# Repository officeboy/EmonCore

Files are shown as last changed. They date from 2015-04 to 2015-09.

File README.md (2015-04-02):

# EmonCore
Open Energy Monitor - All in One for the Spark Core/Photon

Based on work done in the [emonBase/NanodeRF](http://openenergymonitor.org/emon/emonBase/NanodeRF) project, Cinezaster porting [EmonLib](https://github.com/Cinezaster/EmonLib), and Nils Mattisson's [HttpClient](https://github.com/nmattisson/HttpClient) Library

This project aims in the same single unit direction as emonPi but sticks with arduino type programing and aims for a smaller form factor. 

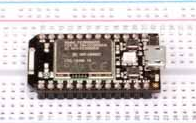
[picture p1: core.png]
spark_core


Currently there is no support for RFM12B or RFM69CW devices.  

### Features

- Built in WiFi
- 8 12-bit Analog Channels
- 73Mhz ARM Cortex M3
- Flash via Web

## Guide

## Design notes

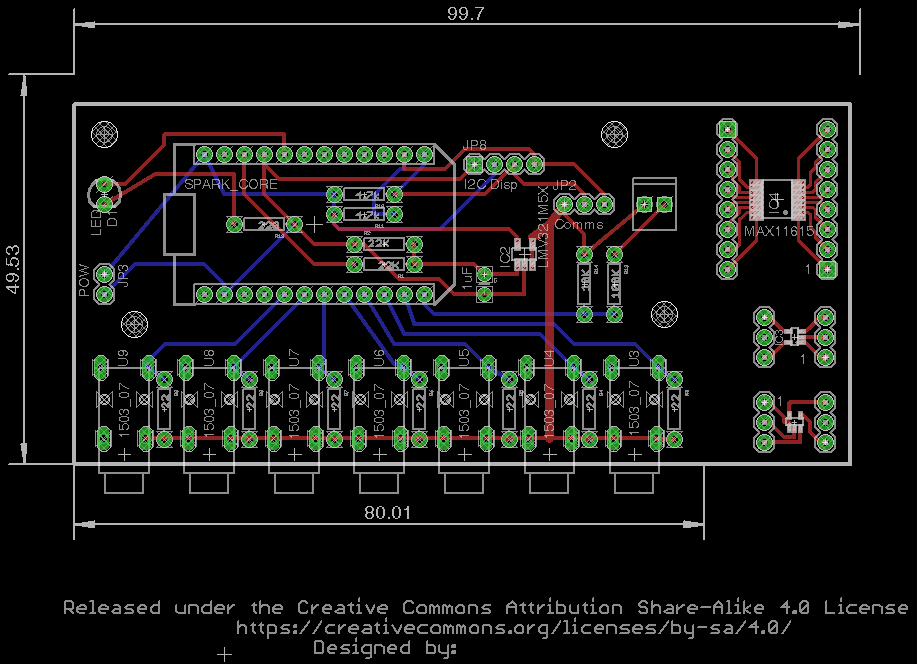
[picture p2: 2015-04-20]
hardware/core_pcb.png

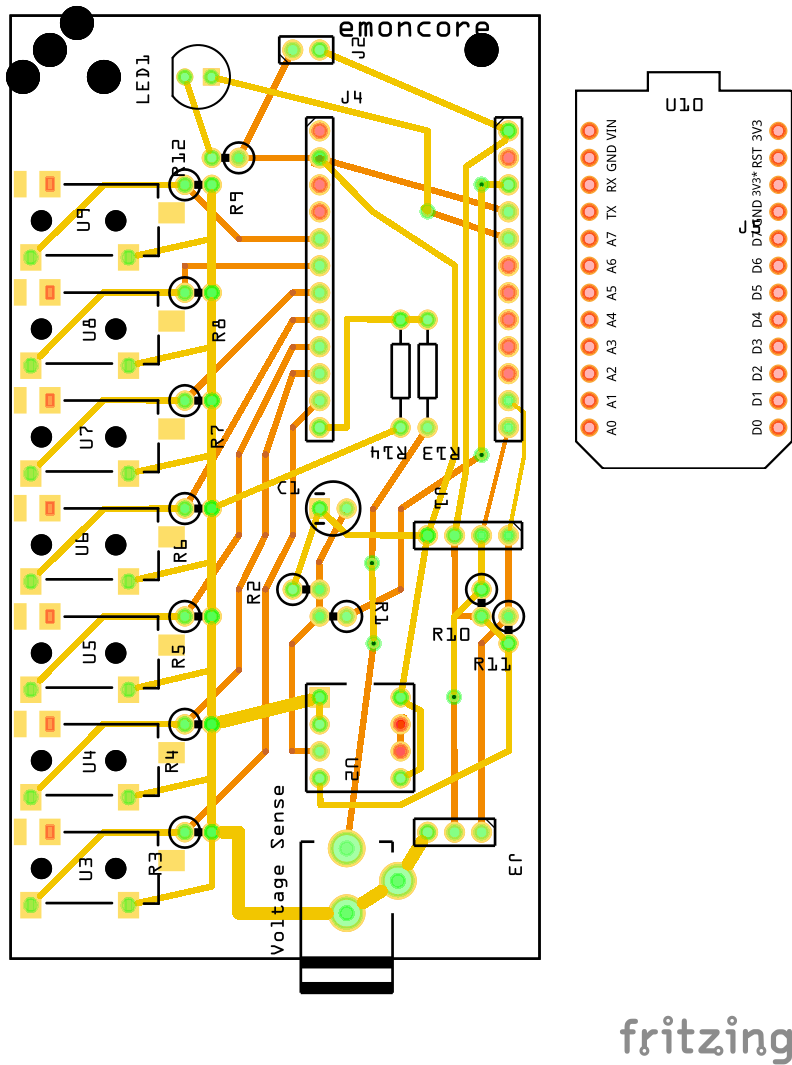
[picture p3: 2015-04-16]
hardware/emoncore_pcb.png

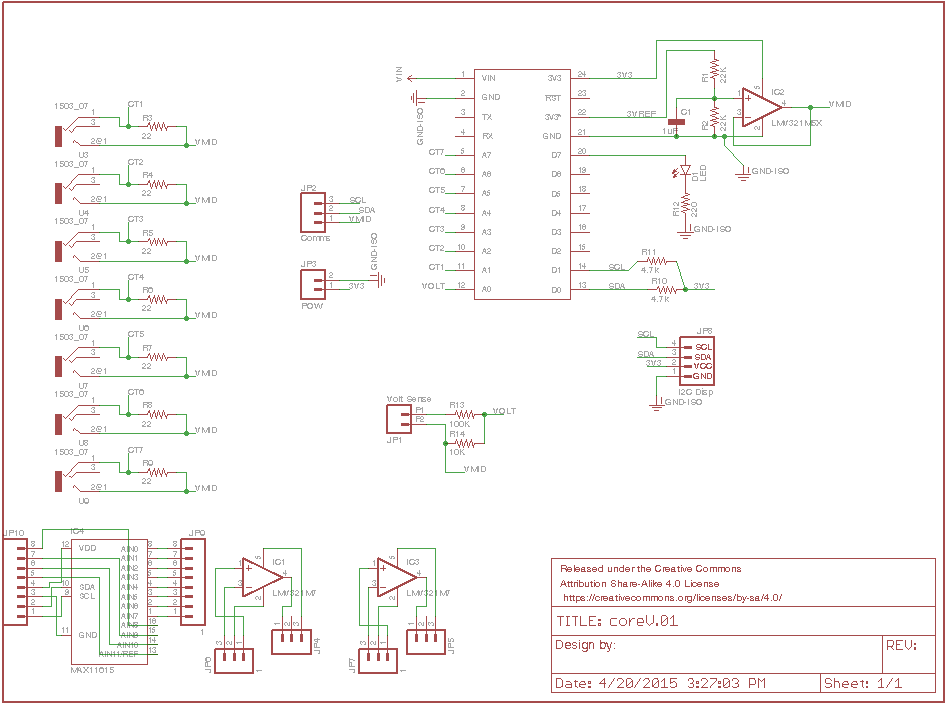
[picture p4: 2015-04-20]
hardware/core_sch.png

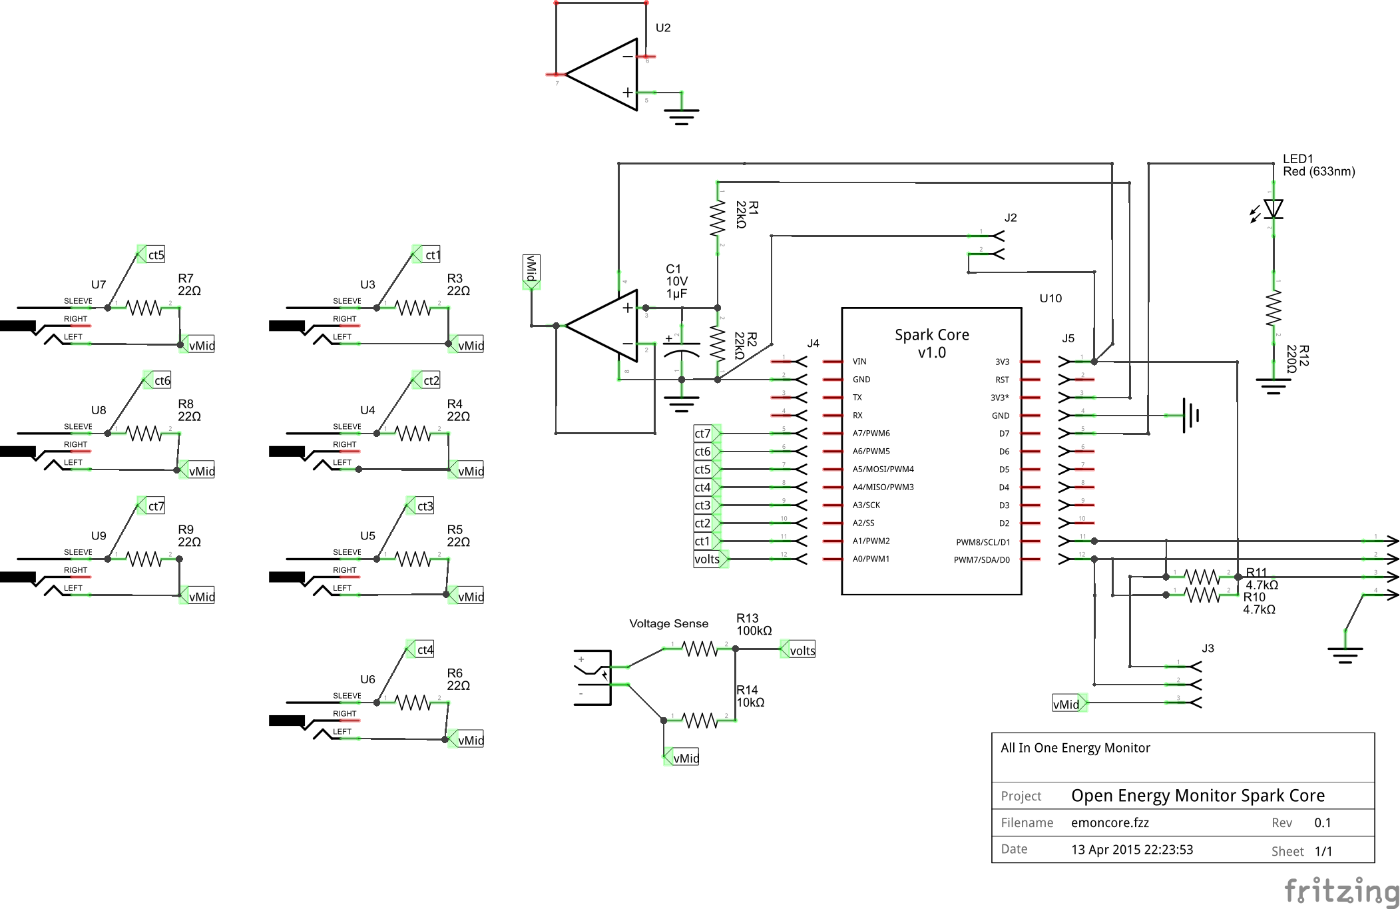
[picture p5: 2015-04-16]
hardware/emoncore_schem.png

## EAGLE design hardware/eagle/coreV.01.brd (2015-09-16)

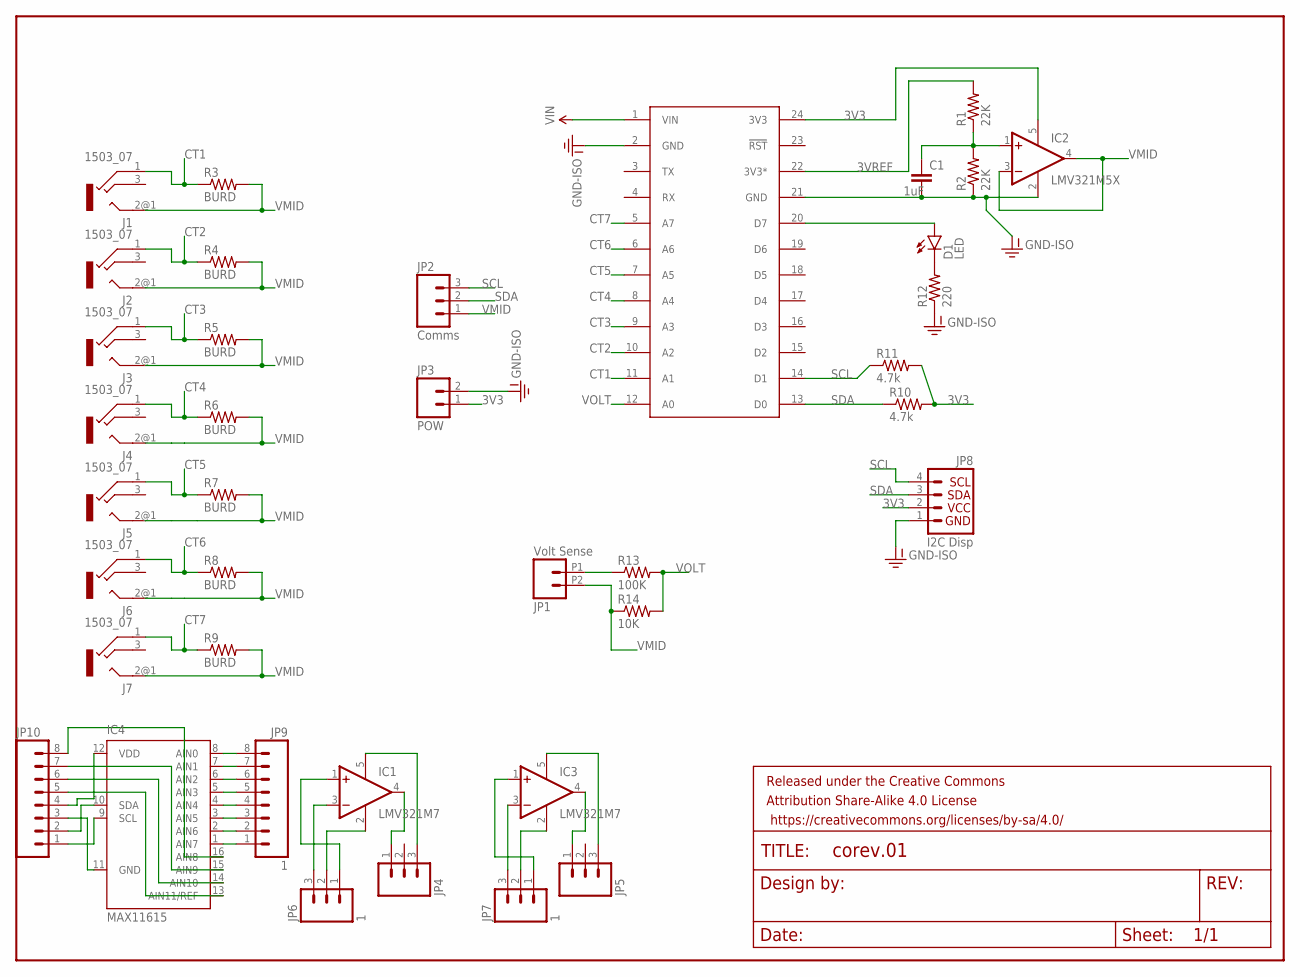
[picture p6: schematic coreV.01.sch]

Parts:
C1: 1uF; CAP-PTH-SMALL
D1: LED; LED3MM
FRAME1: emonCore; CREATIVE_COMMONS
IC1, IC3: LMV321M7; SC70-5L
IC2: LMV321M5X; SOT23-5
IC4: MAX11615; QSOP16
J1, J2, J3, J4, J5, J6, J7: 1503_07
JP1: Volt Sense; 1X02_2.54_SCREWTERM
JP2: Comms; 1X03
JP3: POW; 1X02
JP4, JP5: M03PTH; 1X03
JP6, JP7: 1; 1X03
JP8: I2C Disp; 1X04
JP9: 1; 1X08
JP10: M08SILK_FEMALE_PTH; 1X08
R1, R2: 22K; AXIAL-0.3
R3, R4, R5, R6, R7, R8, R9: BURD; AXIAL-0.3
R10, R11: 4.7k; AXIAL-0.3
R12: 220; AXIAL-0.3
R13: 100K; AXIAL-0.3
R14: 10K; AXIAL-0.3
U$1: SPARK_CORE

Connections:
3V3: IC2.5 (V+), JP3.1, JP8.2, R10.P$2 (2), R11.P$2 (2), U$1.24 (3V3)
3VREF: R1.P$2 (2), U$1.22 (3V3*)
CT1: J1.1, R3.P$1 (1), U$1.11 (A1)
CT2: J2.1, R4.P$1 (1), U$1.10 (A2)
CT3: J3.1, R5.P$1 (1), U$1.9 (A3)
CT4: J4.1, R6.P$1 (1), U$1.8 (A4)
CT5: J5.1, R7.P$1 (1), U$1.7 (A5)
CT6: J6.1, R8.P$1 (1), U$1.6 (A6)
CT7: J7.1, R9.P$1 (1), U$1.5 (A7)
GND-ISO: C1.2, IC2.2 (V-), JP3.2, JP8.1, R2.P$1 (1), R12.P$1 (1), U$1.2 (GND), U$1.21 (GND)
unnamed: D1.K (C), R12.P$2 (2)
unnamed: C1.1, IC2.1 (+IN), R1.P$1 (1), R2.P$2 (2)
unnamed: JP1.P1 (1), R13.P$1 (1)
unnamed: D1.A, U$1.20 (D7)
unnamed: IC3.2 (V-), JP7.2
unnamed: IC3.1 (+IN), JP7.1
unnamed: IC3.3 (-IN), JP7.3
unnamed: IC3.4 (OUT), JP5.1
unnamed: IC1.2 (V-), JP6.2
unnamed: IC3.5 (V+), JP5.3
unnamed: IC1.3 (-IN), JP6.3
unnamed: IC1.1 (+IN), JP6.1
unnamed: IC1.4 (OUT), JP4.1
unnamed: IC1.5 (V+), JP4.3
unnamed: IC4.1 (AIN7), JP9.1
unnamed: IC4.2 (AIN6), JP9.2
unnamed: IC4.3 (AIN5), JP9.3
unnamed: IC4.4 (AIN4), JP9.4
unnamed: IC4.5 (AIN3), JP9.5
unnamed: IC4.6 (AIN2), JP9.6
unnamed: IC4.7 (AIN1), JP9.7
unnamed: IC4.8 (AIN0), JP9.8
unnamed: IC4.9 (SCL), JP10.1
unnamed: IC4.10 (SDA), JP10.2
unnamed: IC4.11 (GND), JP10.3
unnamed: IC4.12 (VDD), JP10.4
unnamed: IC4.13 (AIN11/REF), JP10.5
unnamed: IC4.14 (AIN10), JP10.6
unnamed: IC4.15 (AIN9), JP10.7
unnamed: IC4.16 (AIN8), JP10.8
SCL: JP2.3, JP8.4, R11.P$1 (1), U$1.14 (D1)
SDA: JP2.2, JP8.3, R10.P$1 (1), U$1.13 (D0)
VIN: U$1.1 (VIN)
VMID: IC2.3 (-IN), IC2.4 (OUT), J1.2@1 (2), J2.2@1 (2), J3.2@1 (2), J4.2@1 (2), J5.2@1 (2), J6.2@1 (2), J7.2@1 (2), JP1.P2 (2), JP2.1, R3.P$2 (2), R4.P$2 (2), R5.P$2 (2), R6.P$2 (2), R7.P$2 (2), R8.P$2 (2), R9.P$2 (2), R14.P$1 (1)
VOLT: R13.P$2 (2), R14.P$2 (2), U$1.12 (A0)

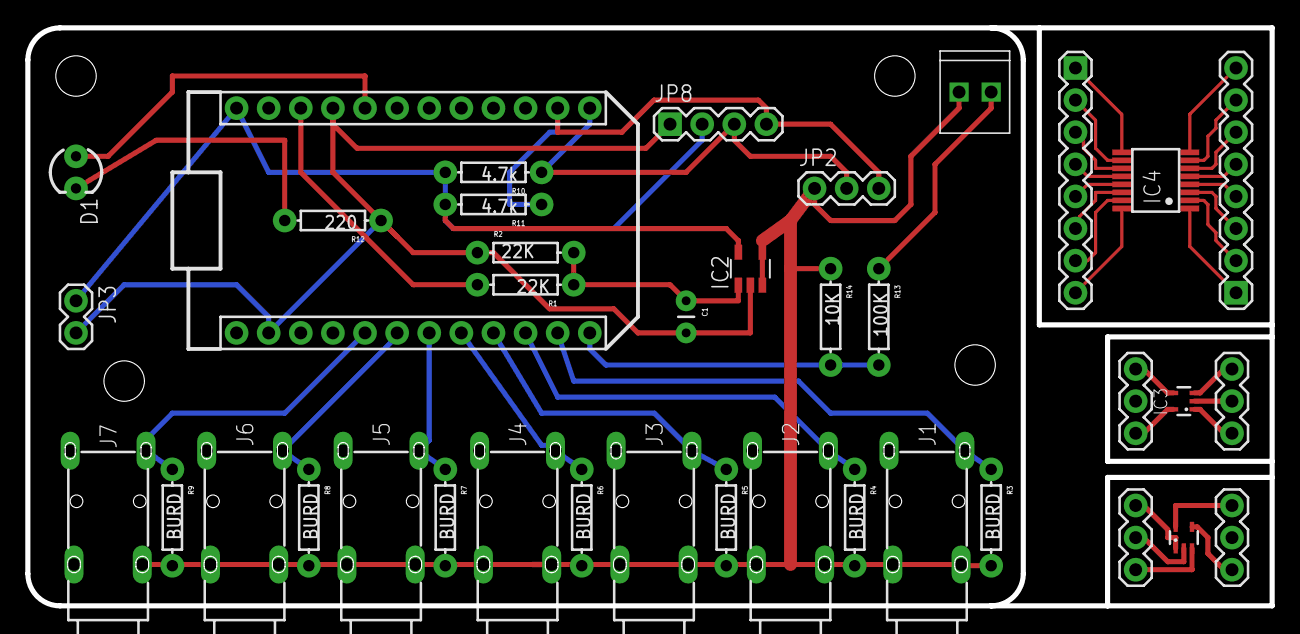
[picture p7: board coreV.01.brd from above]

Board: 2 copper layers, 98.4 x 45.7 mm, 39 parts (0 on the bottom side), 44 nets.

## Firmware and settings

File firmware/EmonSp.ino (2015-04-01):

/*
  
  emonSparkCore V3.4 Discrete Sampling
  
  If AC-AC adapter is detected assume emonTx is also powered from adapter (jumper shorted) and take Real Power Readings and disable sleep mode to keep load on power supply constant
  If AC-AC addapter is not detected assume powering from battereis / USB 5V AC sample is not present so take Apparent Power Readings and enable sleep mode
  
  Transmitt values via WiFi
  
   -----------------------------------------
  Part of the openenergymonitor.org project
  
  Authors: Glyn Hudson & Trystan Lea 
  Builds upon HttpClient, OpenEnergyMonitor's EmonLib library and Spark
  
  Licence: GNU GPL V3
	Modified for Spark Core by Dustin Sellinger
*/

// This #include statement was automatically added by the Spark IDE.
#include "EmonLib/EmonLib.h"             // Include Emon Library
//#include "EmonLib.h"             // Include Emon Library
#include "HttpClient/HttpClient.h"
#include "application.h"
#define cli noInterrupts
#define sei interrupts

//Tinker Variable
//int tinkerDigitalRead(String pin);
//int tinkerDigitalWrite(String command);
//int tinkerAnalogRead(String pin);
//int tinkerAnalogWrite(String command);

/**
* Declaring the variables.
*/
EnergyMonitor ct1, ct2, ct3, ct4;     
//----------------------------SparkEmonTx V3 Settings---------------------------------------------------------------------------------------------------------------
const byte Vrms=                  120;                               // Vrms for apparent power readings (when no AC-AC voltage sample is present)
const byte TIME_BETWEEN_READINGS= 10;            //Time between readings   

//http://openenergymonitor.org/emon/buildingblocks/calibration

const float Ical1=                90.9;                                 // (2000 turns / 22 Ohm burden) = 90.9
const float Ical2=                90.9;                                 // (2000 turns / 22 Ohm burden) = 90.9
const float Ical3=                90.9;                                 // (2000 turns / 22 Ohm burden) = 90.9
const float Ical4=                16.67;                               // (2000 turns / 120 Ohm burden) = 16.67

float Vcal=                       268.97;                             // (230V x 13) / (9V x 1.2) = 276.9 Calibration for UK AC-AC adapter 77DB-06-09 
//float Vcal=276.9;
//const float Vcal=               260;     
unsigned int nextTime =     0;          // Next time to contact the server
int node_id =               0;
const float Vcal_USA=       	  136.5;      //Calibration for my US AC-AC adapter (Nokia 3v charger)
boolean USA=TRUE; 

const float phase_shift=          1.7;
const int no_of_samples=          1480; 
const int no_of_half_wavelengths= 20;
const int timeout=                2000;                               //emonLib timeout 
const int ACAC_DETECTION_LEVEL=   3000;
const int TEMPERATURE_PRECISION=  11;                 //9 (93.8ms),10 (187.5ms) ,11 (375ms) or 12 (750ms) bits equal to resplution of 0.5C, 0.25C, 0.125C and 0.0625C
const byte MaxOnewire=             6;                            // +1 since arrya starts at 0. maximum number of DS18B20 one wire sensors
#define ASYNC_DELAY 375                                          // DS18B20 conversion delay - 9bit requres 95ms, 10bit 187ms, 11bit 375ms and 12bit resolution takes 750ms
//-------------------------------------------------------------------------------------------------------------------------------------------
//-------------------------------------------------------------------------------------------------------------------------------------------

//----------------------------emonTx V3 hard-wired connections--------------------------------------------------------------------------------------------------------------- 
const byte LEDpin =         		   D7;         			// On-board spark core LED
//const byte DS18B20_PWR=            19;                  // DS18B20 Power
//const byte DIP_switch1=            8;                   // Voltage selection 230 / 110 V AC (default switch off 230V)  - switch off D8 is HIGH from internal pullup
//const byte DIP_switch2=            9;                   // RF node ID (default no chance in node ID, switch on for nodeID -1) switch off D9 is HIGH from internal pullup
//const byte battery_voltage_pin=    7;                   // Battery Voltage sample from 3 x AA
const byte pulse_countINT=         1;                   // INT 1 / Dig 3 Terminal Block / RJ45 Pulse counting pin(emonTx V3.4) - (INT0 / Dig2 emonTx V3.2)
const byte pulse_count_pin=        3;                   // INT 1 / Dig 3 Terminal Block / RJ45 Pulse counting pin(emonTx V3.4) - (INT0 / Dig2 emonTx V3.2)
//#define ONE_WIRE_BUS               5                    // DS18B20 Data                     
//-------------------------------------------------------------------------------------------------------------------------------------------

/******  No Temp Support  *********************
//Setup DS128B20
OneWire oneWire(ONE_WIRE_BUS);
DallasTemperature sensors(&oneWire);
byte allAddress [MaxOnewire][8];  // 8 bytes per address
byte numSensors;
**********************************************/
//-------------------------------------------------------------------------------------------------------------------------------------------

#define APIKEY "b5ea4f694e9478fe6c8704a75cd4c2df"

//-----------------------RFM12B / RFM69CW SETTINGS----------------------------------------------------------------------------------------------------
//#define RF_freq RF12_433MHZ                                     // Frequency of RF69CW module can be RF12_433MHZ, RF12_868MHZ or RF12_915MHZ. You should use the one matching the module you have.
//byte nodeID = 10;                                               // emonTx RFM12B node ID
//const int networkGroup = 210;  
typedef struct { 
int power1, power2, power3, power4, Vrms; //temp[MaxOnewire]; 
int pulseCount; 
} PayloadTX;     // create structure - a neat way of packaging data for RF comms
  PayloadTX emontx; 
//-------------------------------------------------------------------------------------------------------------------------------------------
//-------------------------------------------------------------------------------------------------------------------------------------------

HttpClient http;
http_request_t request;
http_response_t response;

//Random Variables 
//boolean settled = false;
boolean CT1, CT2, CT3, CT4, ACAC, debug, DS18B20_STATUS; 
byte CT_count=0;
volatile byte pulseCount = 0;


// Headers currently need to be set at init, useful for API keys etc.
http_header_t headers[] = {
    //  { "Content-Type", "application/json" },
    //  { "Accept" , "application/json" },
      { "Accept" , "*/*"},
    { NULL, NULL } // NOTE: Always terminate headers with NULL
};

void setup() 
{
    pinMode(LEDpin, OUTPUT); 	// Setup indicator LED
	emontx.pulseCount=0;                                        // Make sure pulse count starts at zero
    digitalWrite(LEDpin, HIGH);  

    Serial.begin(9600);

 if (USA==TRUE){                                                                             //if USA mode is true
  Vcal=Vcal_USA;                                                                               //Assume USA AC/AC adatper is being used, set calibration accordingly 
 } 
   
  if (analogRead(1) > 0) {CT1 = 1; CT_count++;} else CT1=0;              // check to see if CT is connected to CT1 input, if so enable that channel
  if (analogRead(2) > 0) {CT2 = 1; CT_count++;} else CT2=0;              // check to see if CT is connected to CT2 input, if so enable that channel
  if (analogRead(3) > 0) {CT3 = 1; CT_count++;} else CT3=0;              // check to see if CT is connected to CT3 input, if so enable that channel
  if (analogRead(4) > 0) {CT4 = 1; CT_count++;} else CT4=0;              //  check to see if CT is connected to CT4 input, if so enable that channel
  
  if ( CT_count == 0) CT1=1;                                              // If no CT's are connect ed CT1-4 then by default read from CT1
  // Quick check to see if there is a voltage waveform present on the ACAC Voltage input
  // Check consists of calculating the RMS from 100 samples of the voltage input.
  delay(10000);            //wait for settle
  digitalWrite(LEDpin,LOW); 
  
  // Calculate if there is an ACAC adapter on analog input 0
  //double vrms = calc_rms(0,1780) * (Vcal * (3.3/1024) );
  double vrms = calc_rms(0,1780) * 0.87;
  if (vrms>90) ACAC = 1; else ACAC=0;
  if (ACAC) 
  {
    for (int i=0; i<10; i++)                                              // indicate AC has been detected by flashing LED 10 times
    { 
      digitalWrite(LEDpin, HIGH); delay(200);
      digitalWrite(LEDpin, LOW); delay(300);
    }
  }
  else 
  {
    delay(1000);
    digitalWrite(LEDpin, HIGH); delay(2000); digitalWrite(LEDpin, LOW);   // indicate DC power has been detected by turing LED on then off
  }
     
    // (ADC input, calibration, phase_shift)
    //ct1.voltage(A0, Vcal, 1.7);  // Voltage: input pin, calibration, phase_shift
    
    // Calibration factor = CT ratio / burden resistance = (100A / 0.05A) / 33 Ohms = 60.606  // (2000 turns / 22 Ohm burden) = 90.9
    //ct1.current(A1, 90.9);       // Current: input pin, calibration.
	
  if (Serial.available()) debug = 1; else debug=0;          //if serial UART to USB is connected show debug O/P. If not then disable serial
  if (debug==1)
  {
    Serial.print("CT 1 Calibration: "); Serial.println(Ical1);
    Serial.print("CT 2 Calibration: "); Serial.println(Ical2);
    Serial.print("CT 3 Calibration: "); Serial.println(Ical3);
    Serial.print("CT 4 Calibration: "); Serial.println(Ical4);
    delay(1000);

    Serial.print("RMS Voltage on AC-AC Adapter input is: ~");
    Serial.print(vrms,0); Serial.println("V");
      
    if (ACAC) 
    {
      Serial.println("AC-AC adapter detected - Real Power measurements enabled");
      Serial.println("assuming powering from AC-AC adapter (jumper closed)");
      if (USA==TRUE) Serial.println("USA mode activated"); 
      Serial.print("Vcal: "); Serial.println(Vcal);
      Serial.print("Phase Shift: "); Serial.println(phase_shift);
    }
     else 
     {
       Serial.println("AC-AC adapter NOT detected - Apparent Power measurements enabled");
       Serial.print("Assuming VRMS to be "); Serial.print(Vrms); Serial.println("V");
       Serial.println("Assuming powering from batteries / 5V USB - power saving mode enabled");
     }  

    if (CT_count==0) Serial.println("NO CT's detected, sampling from CT1 by default");
    else   
    {
      if (CT1) Serial.println("CT 1 detected");
      if (CT2) Serial.println("CT 2 detected");
      if (CT3) Serial.println("CT 3 detected");
      if (CT4) Serial.println("CT 4 detected");
    }
    /************  No Temp Support  ****************
	if (DS18B20_STATUS==1) {Serial.print("Detected "); Serial.print(numSensors); Serial.println(" DS18B20..using this for temperature reading");}
      else Serial.println("Unable to detect DS18B20 temperature sensor");
	************************************************/
	
    #if (RF69_COMPAT)
       Serial.println("RFM69CW Initiated: ");
    #else
      Serial.println("RFM12B Initiated: ");
    #endif
    
   /******  WiFi only for now  ********** 
    Serial.print("Node: "); Serial.print(nodeID); 
    Serial.print(" Freq: "); 
    if (RF_freq == RF12_433MHZ) Serial.print("433Mhz");
    if (RF_freq == RF12_868MHZ) Serial.print("868Mhz");
    if (RF_freq == RF12_915MHZ) Serial.print("915Mhz"); 
    Serial.print(" Network: "); Serial.println(networkGroup);
	**********************************/
    Serial.print("CT1 CT2 CT3 CT4 VRMS/BATT PULSE");
    // if (DS18B20_STATUS==1){Serial.print(" Temperature 1-"); Serial.print(numSensors);}   // No Temp Support
    Serial.println(" "); 
   delay(500);  

  }
  else 
    Serial.end();
  
  
    
  if (CT1) ct1.current(1, Ical1);             // CT ADC channel 1, calibration.  calibration (2000 turns / 22 Ohm burden resistor = 90.909)
  if (CT2) ct2.current(2, Ical2);             // CT ADC channel 2, calibration.
  if (CT3) ct3.current(3, Ical3);             // CT ADC channel 3, calibration. 
  //CT 3 is high accuracy @ low power -  4.5kW Max @ 240V 
  if (CT4) ct4.current(4, Ical4);                                      // CT channel ADC 4, calibration.    calibration (2000 turns / 120 Ohm burden resistor = 16.66)


  if (ACAC)
  {
    if (CT1) ct1.voltage(0, Vcal, phase_shift);          // ADC pin, Calibration, phase_shift
    if (CT2) ct2.voltage(0, Vcal, phase_shift);          // ADC pin, Calibration, phase_shift
    if (CT3) ct3.voltage(0, Vcal, phase_shift);          // ADC pin, Calibration, phase_shift
    if (CT4) ct4.voltage(0, Vcal, phase_shift);          // ADC pin, Calibration, phase_shift
  }

if (DS18B20_STATUS==0) attachInterrupt(pulse_countINT, onPulse, FALLING);     // Attach pulse counting interrupt pulse counting only when no Temperature sensor is connected as they both use the same port
 
   
//Tinker Setup
//Spark.function("digitalread", tinkerDigitalRead);
//Spark.function("digitalwrite", tinkerDigitalWrite);
//Spark.function("analogread", tinkerAnalogRead);
//Spark.function("analogwrite", tinkerAnalogWrite);

} //end SETUP

void loop() 
{
  if (ACAC) {
    delay(200);                         //if powering from AC-AC allow time for power supply to settle    
    emontx.Vrms=0;                      //Set Vrms to zero, this will be overwirtten by CT 1-4
  }
  
  if (CT1) 
  {
   if (ACAC) 
   {
     ct1.calcVI(no_of_half_wavelengths,timeout); emontx.power1=ct1.realPower;
     emontx.Vrms=ct1.Vrms*100;
   }
   else
     emontx.power1 = ct1.calcIrms(no_of_samples)*Vrms;                               // Calculate Apparent Power 1  1480 is  number of sample

  }
  
  if (CT2) 
  {
   if (ACAC) 
   {
     ct2.calcVI(no_of_half_wavelengths,timeout); emontx.power2=ct2.realPower;
     emontx.Vrms=ct2.Vrms*100;
   }
   else
     emontx.power2 = ct2.calcIrms(no_of_samples)*Vrms;                               // Calculate Apparent Power 1  1480 is  number of samples

  }

  if (CT3) 
  {
   if (ACAC) 
   {
     ct3.calcVI(no_of_half_wavelengths,timeout); emontx.power3=ct3.realPower;
     emontx.Vrms=ct3.Vrms*100;
   }
   else
     emontx.power3 = ct3.calcIrms(no_of_samples)*Vrms;                               // Calculate Apparent Power 1  1480 is  number of samples

  }
  

  if (CT4) 
  {
   if (ACAC) 
   {
     ct4.calcVI(no_of_half_wavelengths,timeout); emontx.power4=ct4.realPower;
     emontx.Vrms=ct4.Vrms*100;
   }
   else
     emontx.power4 = ct4.calcIrms(no_of_samples)*Vrms;                               // Calculate Apparent Power 1  1480 is  number of samples

  }
  

/******  No Battery Support for now   ****** 
 if (!ACAC){                                                                                         //read battery voltage if powered by DC
    int battery_voltage=analogRead(battery_voltage_pin) * 0.681322727;     //6.6V battery = 3.3V input = 1024 ADC
    emontx.Vrms= battery_voltage;
  }
********************************************/
  
  
  if (pulseCount)                                                       // if the ISR has counted some pulses, update the total count
  {
    cli();                                                             // Disable interrupt just in case pulse comes in while we are updating the count
    emontx.pulseCount += pulseCount;
    pulseCount = 0;
    sei();                                                            // Re-enable interrupts
  }
 
  if (debug==1) {
    Serial.print(emontx.power1); Serial.print(" ");
    Serial.print(emontx.power2); Serial.print(" ");
    Serial.print(emontx.power3); Serial.print(" ");
    Serial.print(emontx.power4); Serial.print(" ");
    Serial.print(emontx.Vrms); Serial.print(" ");
    Serial.print(emontx.pulseCount); Serial.print(" ");
    /****** No Temp Support *************
	if (DS18B20_STATUS==1){
      for(byte j=0;j<numSensors;j++){
        Serial.print(emontx.temp[j]);
       Serial.print(" ");
      } 
	} 
	********************************************/

    Serial.println(" ");
    delay(50);
  } 
  
  if (ACAC) {digitalWrite(LEDpin, HIGH); delay(200); digitalWrite(LEDpin, LOW);}    // flash LED if powered by AC
  
  send_rf_data();                                                       // *SEND RF DATA* - see emontx_lib
    
    if (ACAC)                                                               //If powered by AC-AC adaper (mains power) then delay instead of sleep
    {
     delay(TIME_BETWEEN_READINGS*1000);
    }
    else                                                                  //if powered by battery then sleep rather than dealy and disable LED to lower energy consumption  
      delay(TIME_BETWEEN_READINGS*1000);                                  // sleep or delay in seconds 
}


void send_rf_data()
{
    // Request path and body can be set at runtime or at setup.
    request.hostname = "emoncms.org";
    request.port = 80;
	request.path = "/input/post.json?apikey="APIKEY"&json={"&emontx"}";
	//request.path = "/input/post.json?apikey="APIKEY"&json={ct1Vrms:"+String(emontx.Vrms)+",ct1Irms:"+String(ct1.Irms)+",NumSamp:"+String(ct1.samp)+",ct1realpower:"+String(ct1.realPower)+",string:"+emontx+"}";
  // Get request
    http.get(request, response, headers);
    
    //Monitoring Options
    //Serial.print("Application>\tResponse status: ");
    //Serial.println(response.status);


    //Serial.print("Application>\tHTTP Response Body: ");
    //Serial.println(response.body);

//  rf12_sleep(RF12_WAKEUP);                                   
//  rf12_sendNow(0, &emontx, sizeof emontx);                           //send temperature data via RFM12B using new rf12_sendNow wrapper
//  rf12_sendWait(2);
//  if (!ACAC) rf12_sleep(RF12_SLEEP);                             //if powred by battery then put the RF module into sleep inbetween readings 
}


double calc_rms(int pin, int samples)
{
  unsigned long sum = 0;
  for (int i=0; i<samples; i++) // 178 samples takes about 20ms
  {
    int raw = (analogRead(0)-512);
    sum += (unsigned long)raw * raw;
  }
  double rms = sqrt((double)sum / samples);
  return rms;
}

// The interrupt routine - runs each time a falling edge of a pulse is detected
void onPulse()                  
{
   pulseCount++;
}

/**********  No Temp Support  **************************
int get_temperature(byte sensor)                
{
  float temp=(sensors.getTempC(allAddress[sensor]));
  if ((temp<125.0) && (temp>-55.0)) return(temp*10);            //if reading is within range for the sensor convert float to int ready to send via RF
  }
********************************************************/

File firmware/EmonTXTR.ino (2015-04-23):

// This #include statement was automatically added by the Spark IDE.
#include "sh1106/sh1106.h"  //Display library
#include "EmonLib/EmonLib.h"             // Include Emon Library
#include "HttpClient/HttpClient.h"
#include "application.h"

//Tinker Variable
int tinkerDigitalRead(String pin);
int tinkerDigitalWrite(String command);
int tinkerAnalogRead(String pin);
//int tinkerAnalogWrite(String command);


/**
* Declaring the variables.
*/
unsigned int nextTime =     0;          // Next time to contact the server
int node_id =               0;
const float Vcal=           136.5;      //Calibration for my US AC-AC adapter (Nokia 3v charger)
const int LEDpin =          D7;         // On-board spark core LED
const int no_of_half_wavelengths= 20;
const int timeout=                2000;                               //emonLib timeout 

#define APIKEY "<Your Key Here>"
//String rssi = 0;

HttpClient http;
http_request_t request;
http_response_t response;
EnergyMonitor ct1, ct2, ct3, ct4, ct5, ct6, ct7;             // Create an instance for each channel
int power1, power2, power3, power4, Vrms, DVrms; 

volatile boolean g_writeValue = false;
volatile int g_displayValue = 0;

sh1106_lcd *glcd = NULL;
char charV[10], charCt1[10], charCt2[10], charCt3[10], charCt4[10];



// Headers currently need to be set at init, useful for API keys etc.
http_header_t headers[] = {
    //  { "Content-Type", "application/json" },
    //  { "Accept" , "application/json" },
      { "Accept" , "*/*"},
    { NULL, NULL } // NOTE: Always terminate headers with NULL
};


void setup() {
    // Setup indicator LED
    pinMode(LEDpin, OUTPUT);
    digitalWrite(LEDpin, HIGH);

    Serial.begin(9600);
    
  glcd = sh1106_lcd::getInstance();

  if (glcd != NULL)
  {
    glcd->ClearScreen();
  }


    // (ADC input, calibration, phase_shift)
    ct1.voltage(A0, Vcal, 1.7);  // Voltage: input pin, calibration, phase_shift
    ct2.voltage(A0, Vcal, 1.7);
    ct3.voltage(A0, Vcal, 1.7);
    ct4.voltage(A0, Vcal, 1.7);
    //ct5.voltage(A0, Vcal, 1.7);
    //ct6.voltage(A0, Vcal, 1.7);
    //ct7.voltage(A0, Vcal, 1.7);
    
    // Calibration factor = CT ratio / burden resistance = (100A / 0.05A) / 33 Ohms = 60.606  // (2000 turns / 22 Ohm burden) = 90.9
    ct1.current(A1, 187.5);  //=6000 turns / 32omh - sct-019     Current: input pin, calibration. 
    ct2.current(A2, 187.5);  //=6000 turns / 32ohm - sct-019
    ct3.current(A3, 40);  //= 2000 turns / 50ohm - sct-013
    ct4.current(A4, 40);  //= 2000 turns / 50ohm - sct-013
    //ct5.current(A5, 90.9);
    //ct6.current(A6, 90.9);
    //ct7.current(A7, 90.9);
    

//Tinker Setup
    Spark.function("digitalread", tinkerDigitalRead);
    Spark.function("digitalwrite", tinkerDigitalWrite);
    Spark.function("analogread", tinkerAnalogRead);
    //Spark.function("analogwrite", tinkerAnalogWrite);

   
    delay(1000);
    digitalWrite(LEDpin,LOW);

}

void loop() {
    if (nextTime > millis()) {
        return;
    }

    // Available properties: ct1.realPower, ct1.apparentPower, ct1.powerFactor, ct1.Irms and ct1.Vrms
    ct1.calcVI(no_of_half_wavelengths,timeout); Vrms = ct1.Vrms*100; // Calculate all. No.of half wavelengths (crossings), time-out
    ct2.calcVI(no_of_half_wavelengths,timeout);
    ct3.calcVI(no_of_half_wavelengths,timeout);
    ct4.calcVI(no_of_half_wavelengths,timeout);
    
    
    
    
    //Send WiFi Signal Strength 
    //String rssi = String(WiFi.RSSI(), DEC);   (rssi:"+String(rssi)+",)  //Needs testing, system locking up. 
    
    nextTime = millis() + 10000;  //Reset counter before sending off data so network or display issues don't hold things up.
    
    send_data();    //Send data off to web
    update_display();  // Send data to screen (needs IF statment to check for display)
   
}


void send_data()
{
 
  // Request path and body can be set at runtime or at setup.
  request.hostname = "emoncms.org";
  request.port = 80;
  request.path = "/input/post.json?apikey="APIKEY"&json={Vrms:"+String(Vrms)+",ct1realpower:"+String(ct1.realPower)+",ct2realpower:"+String(ct2.realPower)+",ct3realpower:"+String(ct3.realPower)+",ct4realpower:"+String(ct4.realPower)+"}";

  // The library also supports sending a body with your request:
  //request.body = "{\"key\":\"value\"}";

  // Get request
  http.get(request, response, headers);

  //Monitoring Options
  //Serial.print("Application>\tResponse status: ");
  //Serial.println(response.status);

  //Serial.print("Application>\tHTTP Response Body: ");
  //Serial.println(response.body);

  digitalWrite(LEDpin,HIGH);
  delay(200);
  digitalWrite(LEDpin,LOW);
}

void update_display()
{
char str[30]; char str1[30]; char str2[30];
  DVrms = Vrms/100;
  String(DVrms).toCharArray(charV, 4); // Convert string to char for display output.
  String(ct1.realPower).toCharArray(charCt1, 5); // ct1 watts, digits
  String(ct2.realPower).toCharArray(charCt2, 5); // ct2 watts, digits
  String(ct3.realPower).toCharArray(charCt3, 4); // ct3 watts, digits
  String(ct4.realPower).toCharArray(charCt4, 4); // ct4 watts, digits
  strcpy (str," Voltage=");
  strcat (str,charV);
  
  strcpy (str1," ct1="); //new line
  strcat (str1,charCt1);
  strcat (str1,"w;");
  
  strcat (str1," ct2="); 
  strcat (str1,charCt2);
  strcat (str1,"w ");
  
  strcpy (str2," Ct3=");//new line
  strcat (str2,charCt3);
  strcat (str2,"w; ");
  
  strcat (str2," Ct4="); 
  strcat (str2,charCt4);
  strcat (str2,"w ");

  glcd->PrintLine("");
  glcd->PrintLine(str);   //prints the strings we have been building
  glcd->PrintLine(str1);
  glcd->PrintLine(str2);
  //glcd->DrawRectangle(2, 12, 114, 26, 1); // draw a box around the text
  //glcd->Show();
}


//Tinker Code
int tinkerDigitalRead(String pin) {
    int pinNumber = pin.charAt(1) - '0';
    if (pinNumber< 0 || pinNumber >7) return -1;
    if(pin.startsWith("D")) {
        pinMode(pinNumber, INPUT_PULLDOWN);
        return digitalRead(pinNumber);}
    else if (pin.startsWith("A")){
        pinMode(pinNumber+10, INPUT_PULLDOWN);
        return digitalRead(pinNumber+10);}
    return -2;}

int tinkerDigitalWrite(String command){
    bool value = 0;
    int pinNumber = command.charAt(1) - '0';
    if (pinNumber< 0 || pinNumber >7) return -1;
    if(command.substring(3,7) == "HIGH") value = 1;
    else if(command.substring(3,6) == "LOW") value = 0;
    else return -2;
    if(command.startsWith("D")){
        pinMode(pinNumber, OUTPUT);
        digitalWrite(pinNumber, value);
        return 1;}
    else if(command.startsWith("A")){
        pinMode(pinNumber+10, OUTPUT);
        digitalWrite(pinNumber+10, value);
        return 1;}
    else return -3;}
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

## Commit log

2015-03-27 First Working
    Gets analog reading from A0 and A1
    Enables tinker so you can read and set values without sensor (does need
    some jumper wires since you can't write and read from the same pin)
2015-04-01 Revert "Start of rebase on emontx3 from nanodeRF"
    This reverts commit 08fe7cee7cd59ef0e31d750fc931684b249a59a1.
    [EmonTXTR.ino]
2015-04-01 Revert "Revert "Start of rebase on emontx3 from nanodeRF""
    This reverts commit 33eafbb75076938f1f11204168eaa1d54870827a.
    [EmonTXTR.ino]
2015-04-01 Revert "Revert "Revert "Start of rebase on emontx3 from nanodeRF"""
    This reverts commit 871d2c3ea81144d46abe9197237618a9d577d539.
    [EmonTXTR.ino]
2015-04-01 Undoing my poorly chosen work from yesterday.
    Yo Dog, I hear you like reverts...
    I don't know if I will get the hang of this.
    [EmonTXTR.ino]
2015-04-02 Giving props
2015-04-14 Board layout changes
    and turned some packages into pin-outs.
    [emoncore.fzz]
2015-04-14 Pics and DRC ok
    [emoncore.fzz]
2015-04-16 Shrank PCB and added header pins
    changed a few names too
    [emoncore.fzz]
2015-04-20 Eagle design files
    to many issues with getting a good footprint in fritzing.
2015-04-22 Left a few bugs in update_display
    [EmonTXTR.ino]
2015-09-16 added work files
    Hopefully these can be usefull
    [coreV.01.brd, coreV.01.sch, emoncore v1.fzz]

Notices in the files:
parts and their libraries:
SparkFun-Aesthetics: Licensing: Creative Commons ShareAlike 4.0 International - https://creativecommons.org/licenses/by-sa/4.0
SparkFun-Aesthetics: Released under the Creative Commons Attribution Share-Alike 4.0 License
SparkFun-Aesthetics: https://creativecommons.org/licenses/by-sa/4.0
